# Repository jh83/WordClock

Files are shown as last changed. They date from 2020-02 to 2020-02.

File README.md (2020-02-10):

# WordClock

Some time ago i decided to build my own "WordClock" and I must say that im quite happy with the results:

Image of WordClock

The hardware consists of:

- ESP8266, as the "brain". Wifi and NTP connected and hosts a web page. Th webpage is used to configure time zone, NTP sync frequency, led strength among other things.
- ~~WS2812 LED strip cut to size to form a 14x10 matrix.~~ Custom made WS2813 LED panel (replaced the previous ws2812 strip due to dead led).
- Radar module (RCWL-0516) to detect movements. If movement isn't detected in a configurable amount of time (thru the web interface) then the LEDs are turned off.
  - Radar modules can "see thru" objects which makes it possible to mount behind the plywood front and have *working* results. Compared to PIR sensors that needs an open view.
- Lasercut 3mm plywood. A 40w laser was used in my case
- Mahogny frame. Cut from a bigger piece of wood and made into a frame.
- A white plastic bag used as a *diffuser* between the LED and the plywood front. You want this layer as thin as possible so that there isn't any light traveling to other characters thru the diffuser itself.
- A custom/modified stencil font family was created by me. A stencil font is required since parts of the letters otherwise will be lost after lasercutting

The size of the led matrix is around 9x9cm which makes each individual letter very small - around 6 mm tall and 5 mm wide.

You *might* be able to cut the plywood with a CNC router with a really tiny end mill, but the forces from the end mill might damage the tiny parts of the letters.

Tools/knowledge needed:

- A lasercutter (or ordering a custom laser cut part from internet).
- Basic woodworking tools and some wood glue.
- Basic knowledge about flashing Arduino code onto a ESP8266.
- Basic soldering skills.

Cost:

- Lasercut plywood.
  - Cheap if you own a laser cutter.
  - Price unknown if you need someone to lasercut it for you.
- LED Board
  - I had mine fabricated thru JLCPCB which also does assembly. The PCB with 140 WS2813, 140 capacitors and 140 resistors soldered onto it was about 17 USD plus shipping for a finished product.
- ESP8266.
  - I used a Wemos Mini pro since that was what I had in stock. Costs around 10 USD
- Radar sensor.
  - Around 2 USD
- Mahogny.
  - Expensive, atleast here in sweden.

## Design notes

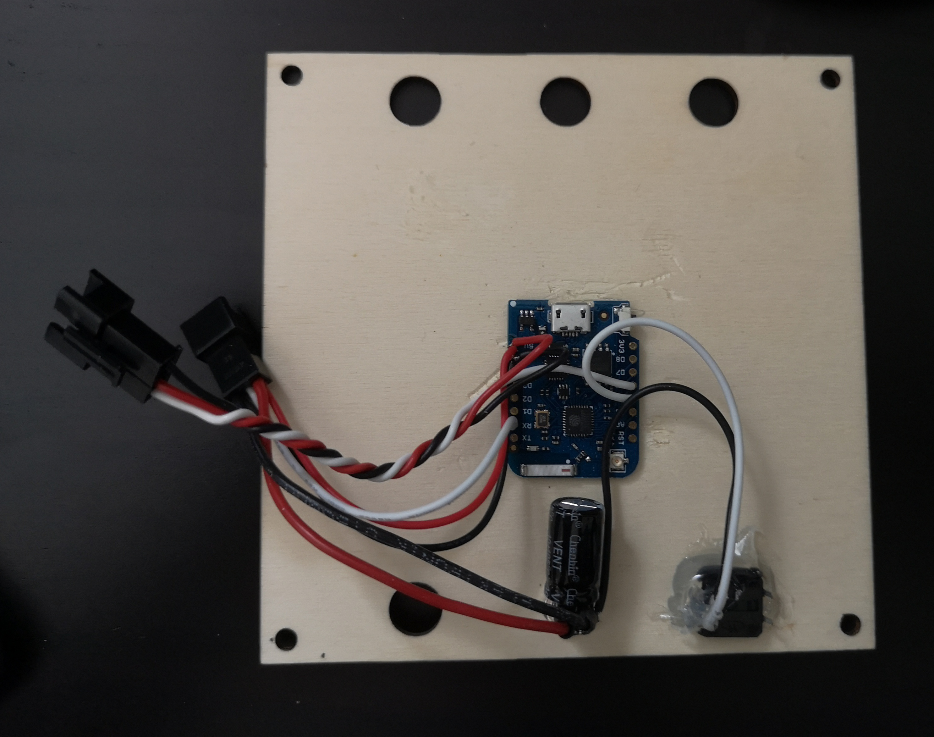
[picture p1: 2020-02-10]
images/backCoverWithElectronics.jpg

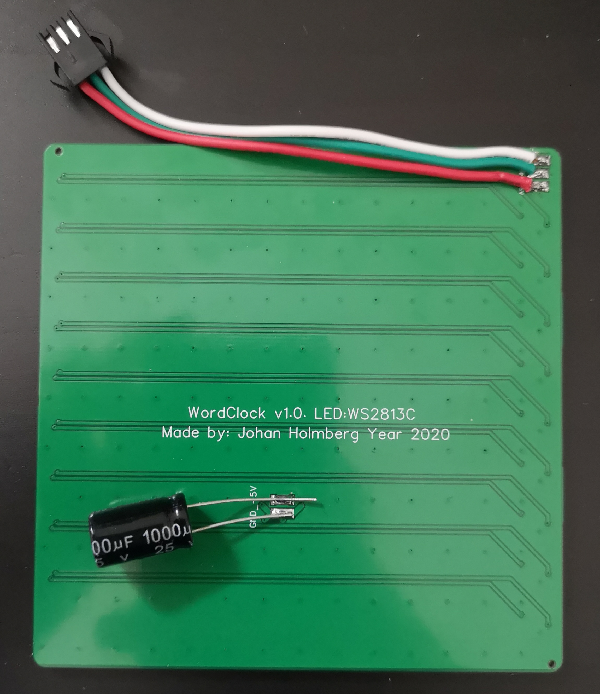
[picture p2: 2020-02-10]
images/ledPanelBack.jpg

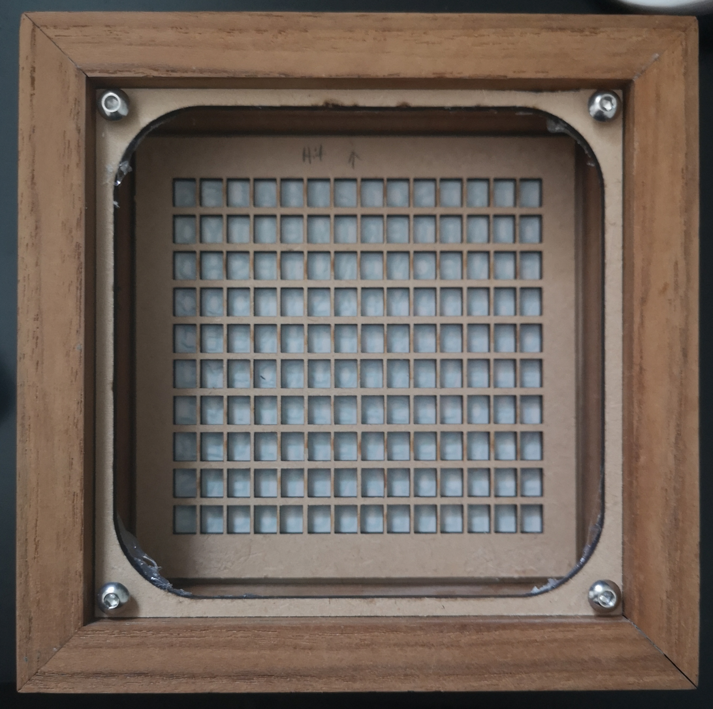
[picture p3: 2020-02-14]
images/Inside.jpg

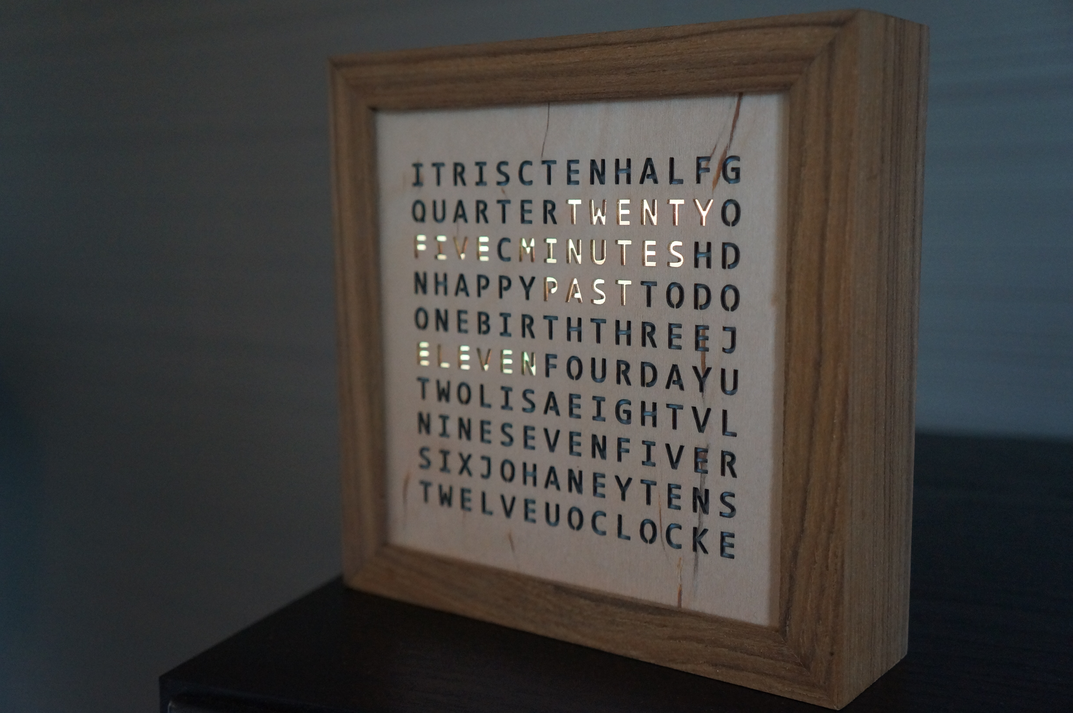
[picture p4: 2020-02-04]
images/WordClock_1_highres.JPG

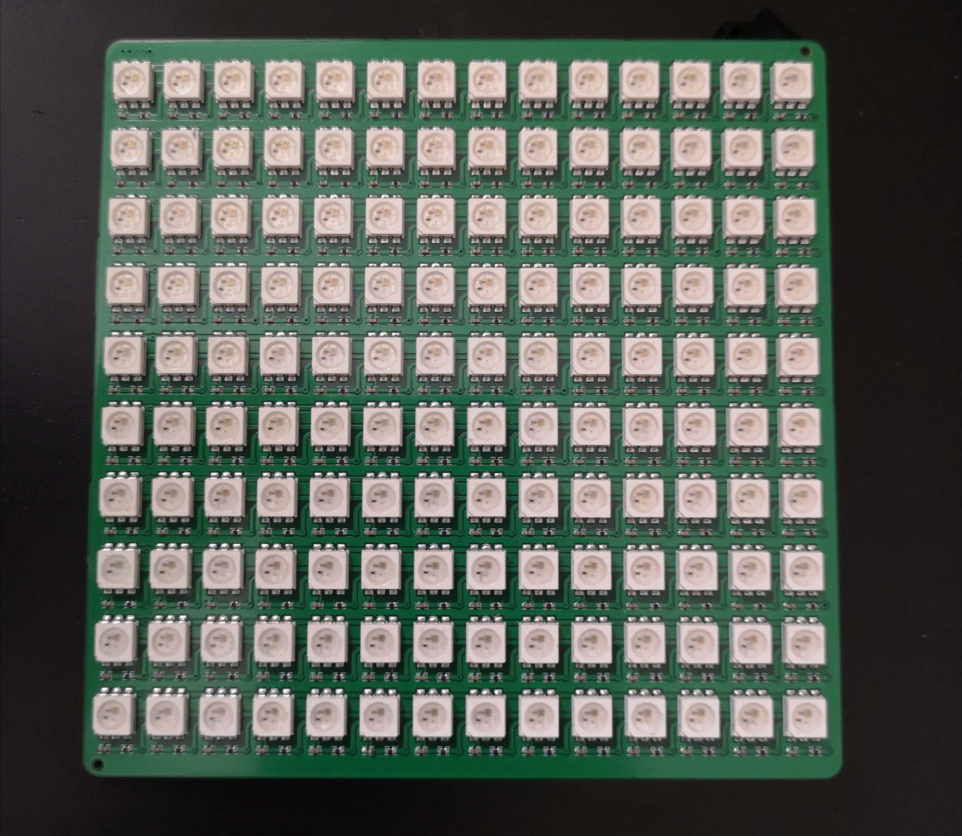
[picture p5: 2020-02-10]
images/ledPanelFront.jpg

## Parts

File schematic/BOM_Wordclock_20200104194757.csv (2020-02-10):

ID | Name | Designator | Footprint | Quantity | Manufacturer Part | Manufacturer | Supplier | Supplier Part | LCSC Assembly
2 | WS2813C | LED1,LED140,LED139,LED138,LED137,LED136,LED135,LED3,LED134,LED133,LED4,LED132,LED131,LED5,LED130,LED129,LED6,LED128,LED127,LED7,LED126,LED125,LED8,LED124,LED123,LED9,LED122,LED121,LED10,LED120,LED119,LED11,LED118,LED117,LED12,LED116,LED115,LED13,LED114,LED113,LED14,LED15,LED112,LED111,LED110,LED109,LED16,LED17,LED108,LED107,LED18,LED106,LED105,LED19,LED104,LED103,LED20,LED102,LED101,LED21,LED100,LED99,LED22,LED98,LED97,LED23,LED96,LED95,LED24,LED94,LED93,LED25,LED92,LED91,LED26,LED90,LED89,LED27,LED88,LED87,LED28,LED86,LED85,LED84,LED83,LED29,LED30,LED82,LED81,LED31,LED80,LED79,LED32,LED78,LED77,LED33,LED76,LED75,LED34,LED74,LED73,LED35,LED72,LED2,LED36,LED71,LED70,LED37,LED69,LED68,LED38,LED67,LED66,LED39,LED65,LED64,LED40,LED63,LED62,LED41,LED61,LED60,LED42,LED59,LED58,LED43,LED57,LED56,LED44,LED55,LED54,LED45,LED53,LED52,LED46,LED51,LED50,LED47,LED49,LED48 | LED-WS2813B-B | 140 | WS2813C | Worldsemi | LCSC | C194323
3 | 100nF | C48,C71,C49,C50,C46,C51,C52,C45,C53,C54,C44,C55,C56,C43,C57,C58,C42,C59,C60,C41,C61,C62,C40,C63,C64,C39,C65,C66,C38,C67,C68,C37,C69,C70,C36,C35,C72,C73,C34,C74,C75,C33,C76,C77,C32,C78,C79,C31,C80,C81,C30,C82,C29,C83,C84,C85,C28,C86,C87,C27,C88,C89,C26,C90,C91,C25,C92,C93,C24,C94,C47,C95,C23,C96,C97,C22,C98,C99,C21,C100,C101,C20,C102,C103,C19,C104,C105,C18,C106,C107,C17,C108,C16,C109,C110,C111,C15,C112,C14,C113,C114,C13,C115,C116,C12,C117,C118,C11,C119,C120,C10,C121,C122,C9,C123,C124,C8,C125,C126,C7,C127,C128,C6,C129,C130,C5,C131,C132,C4,C133,C134,C3,C135,C136,C137,C138,C2,C139,C1,C140 | 0402' | 140 | CL05B104KO5NNNC | SAMSUNG | LCSC | C1525 | Yes
5 | 200 | R23,R71,R95,R59,R41,R96,R22,R72,R97,R34,R44,R98,R21,R73,R99,R60,R48,R100,R20,R74,R101,R33,R54,R102,R19,R75,R103,R61,R40,R104,R18,R76,R105,R32,R49,R106,R17,R77,R107,R62,R51,R108,R78,R31,R109,R16,R55,R110,R15,R79,R111,R63,R39,R112,R80,R30,R113,R14,R43,R114,R81,R64,R115,R13,R45,R116,R82,R56,R117,R12,R65,R118,R83,R29,R119,R11,R38,R120,R84,R28,R121,R10,R46,R122,R85,R66,R123,R9,R52,R124,R86,R27,R125,R8,R57,R126,R87,R67,R127,R7,R37,R128,R88,R26,R129,R6,R42,R130,R89,R68,R131,R5,R47,R132,R90,R25,R133,R4,R58,R134,R91,R69,R135,R3,R36,R136,R2,R92,R137,R1,R24,R138,R50,R93,R139,R70,R53,R140,R35,R94 | 0402' | 140 | 0402WGF2000TCE | UniOhm | LCSC | C25087 | Yes

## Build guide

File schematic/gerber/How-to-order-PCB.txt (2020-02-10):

How to Order PCB

Please refer to:
https://docs.easyeda.com/en/PCB/Order-PCB

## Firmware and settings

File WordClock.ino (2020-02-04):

#include <Ticker.h>
#include <Time.h>
#include <TimeLib.h>
#include <ArduinoOTA.h>
#include <EEPROM.h>
#include <ESP8266WiFiMulti.h>
#include <WiFiUdp.h>
#include <ESP8266WiFi.h>
#include <WiFiServer.h>
#include <WiFiClient.h>
#include <ESP8266WebServer.h>
#include <ESP8266mDNS.h>

#include <ws2812_i2s.h>

#include "settings.h"
#include "mainPage.h"
//#include "display.h"
#include "ntp.h"
#include "staticScreens.h"

#define SETUP_PIN 14
#define RADAR_PIN 12

#define MODE_SETUP 0
#define MODE_CLOCK 1
int clockMode;
bool isUpdating = false;
bool debugEnabled = true;
long lastMovement = 0;
int movement = 0;
String lastMovementDateTime, lastMovementDate, lastMovementTime;

ESP8266WebServer server (80);

String httpUpdateResponse;

time_t prevDisplay = 0;

void setupAP() {
  Serial.println("Entering Setup Mode.");
  Serial.print("Initiating AP: ");
  Serial.println(WIFI_AP_NAME);
  Serial.println("IP: 192.168.4.1");
  clockMode = MODE_SETUP;
  WiFi.mode(WIFI_AP);
  WiFi.softAP(WIFI_AP_NAME);
  //  displayAP();
}


void setupSTA()
{
  char ssid[32];
  char psk[64];
  memset(ssid, 0, 32);
  memset(psk, 0, 64);
  // displayBusy(1);

  clockMode = MODE_CLOCK;
  WiFi.mode(WIFI_STA);

  settings.ssid.toCharArray(ssid, 32);
  settings.psk.toCharArray(psk, 64);
  if (WiFi.status() != WL_CONNECTED) {
    if (settings.psk.length()) {
      WiFi.begin(ssid, psk);
    } else {
      WiFi.begin(ssid);
    }
  }

  Serial.print("Connecting to SSID: ");
  Serial.println(ssid);

  // Wait for WiFi to connect
  while (WiFi.status() != WL_CONNECTED) {
    delay(1000);

    // Show the no WiFi screen
    showNoWifi();

    // Print some debug info
    Serial.print(WiFi.status());
    Serial.print(".");
  }

  // Once connected to WiFi
  Serial.print("Connected to WiFi. IP: ");
  Serial.println(WiFi.localIP());

  // Cleard the display
  clearDisplay();

  //  stopDisplayBusy();
  //  displayDash();
}

void setupWiFi() {
  // Wait up to 5s for GPIO0 to go low to enter AP/setup mode.
  //  displayBusy(0);
  while (millis() < 5000) {
    if (digitalRead(SETUP_PIN) == 0 || !settings.ssid.length()) {
      //      stopDisplayBusy();
      Serial.println("Setup Button pushed.");
      return setupAP();
    }
    delay(100);
  }
  //  stopDisplayBusy();
  setupSTA();
}


void handleRoot() {

  String s = MAIN_page;
  s.replace("@@SSID@@", settings.ssid);
  s.replace("@@PSK@@", settings.psk);
  s.replace("@@TZ@@", String(settings.timezone));
  s.replace("@@YEAR@@", String(year()));
  s.replace("@@MONTH@@", String(month()));
  s.replace("@@DAY@@", String(day()));
  s.replace("@@HOUR@@", String(hour()));
  s.replace("@@MIN@@", String(minute()));
  s.replace("@@SECOND@@", String(second()));
  s.replace("@@LASTMOVEMENT@@", lastMovementDateTime);
  s.replace("@@NTPSRV@@", settings.timeserver);
  s.replace("@@NTPINT@@", String(settings.interval));
  s.replace("@@SYNCSTATUS@@", timeStatus() == timeSet ? "OK" : "Overdue");
  s.replace("@@CLOCKNAME@@", settings.name);
  s.replace("@@ITIS@@", settings.showItIs == 1 ? "checked" : "");
  s.replace("@@DIMLVL@@", String(settings.dimLevel));
  s.replace("@@LEDTIME@@", String(settings.ledTime));
  s.replace("@@UPDATERESPONSE@@", httpUpdateResponse);
  httpUpdateResponse = "";
  server.send(200, "text/html", s);
}

void handleForm() {
  String update_wifi = server.arg("update_wifi");
  String t_ssid = server.arg("ssid");
  String t_psk = server.arg("psk");
  String t_timeserver = server.arg("ntpsrv");
  t_timeserver.toCharArray(settings.timeserver, EEPROM_TIMESERVER_LENGTH, 0);
  if (update_wifi == "1") {
    settings.ssid = t_ssid;
    settings.psk = t_psk;
  }
  String tz = server.arg("timezone");

  if (tz.length()) {
    settings.timezone = tz.toInt();
  }

  time_t newTime = getNtpTime();
  if (newTime) {
    setTime(newTime);
  }
  String syncInt = server.arg("ntpint");
  settings.interval = syncInt.toInt();

  settings.name = server.arg("clockname");
  settings.name.replace("+", " ");

  settings.showItIs = server.arg("showitis").toInt();

  settings.dimLevel = server.arg("dimlvl").toInt();

  settings.ledTime = server.arg("ledTime").toInt();

  httpUpdateResponse = "The configuration was updated.";

  server.sendHeader("Location", "/");
  server.send(302, "text/plain", "Moved");

  settings.Save();

  updateDisplay();

  if (update_wifi == "1") {
    delay(500);
    setupWiFi();
  }
}

void setup() {

  if (debugEnabled == true)
  {
    Serial.begin(115200);
    Serial.println();
    Serial.println("Booting");
  }

  //Load settings from EEPROM
  Serial.println("Loading settings from EEPROM");
  settings.Load();

  // Hostname defaults to esp8266-[ChipID]
  String deviceName = settings.name;
  char deviceNameToCharArray[sizeof(deviceName)];
  deviceName.toCharArray(deviceNameToCharArray, sizeof(deviceNameToCharArray));
  ArduinoOTA.setHostname(deviceNameToCharArray);
  //  ArduinoOTA.setHostname(deviceName);

  // No authentication by default
  // ArduinoOTA.setPassword((const char *)"123");

  ArduinoOTA.onStart([]() {
    Serial.println("Start");
    isUpdating = true;
  });
  ArduinoOTA.onEnd([]() {
    Serial.println("End");
    isUpdating = false;
  });
  ArduinoOTA.onProgress([](unsigned int progress, unsigned int total) {
    Serial.printf("Progress: %u%%\n", (progress / (total / 100)));
  });
  ArduinoOTA.onError([](ota_error_t error) {
    Serial.printf("Error[%u]: ", error);
    if (error == OTA_AUTH_ERROR) Serial.println("Auth Failed");
    else if (error == OTA_BEGIN_ERROR) Serial.println("Begin Failed");
    else if (error == OTA_CONNECT_ERROR) Serial.println("Connect Failed");
    else if (error == OTA_RECEIVE_ERROR) Serial.println("Receive Failed");
    else if (error == OTA_END_ERROR) Serial.println("End Failed");
    isUpdating = false;
  });
  ArduinoOTA.begin();

  // Initiate display and make sure that all LEDs are off
  leds.init(NUM_LEDS);
  clearDisplay();

  // Declare Pin Modes
  pinMode(SETUP_PIN, INPUT_PULLUP);
  pinMode(RADAR_PIN, INPUT);
  digitalWrite(SETUP_PIN, HIGH);

  // Attach the interrupt for the movement sensor
  attachInterrupt(RADAR_PIN, movementDetected, CHANGE);

  setupWiFi();
  setupTime();
  server.on("/", handleRoot);
  server.on("/form", handleForm);
  server.begin();
}


void loop() {
  ArduinoOTA.handle();
  server.handleClient();

  if (isUpdating == false)
  {
    //Serial.println("1");
    //if (displayIP()) return;
    if (clockMode == MODE_CLOCK) {
      if (timeStatus() != timeNotSet) {
        if (minute() != prevDisplay) { //update the display only if time has changed
          prevDisplay = minute();
          updateDisplay();
          //          displayClock();
        }
      }
    }

    //turn on/off display depending on movement
    // If movement is detected, then turn the display on by setting the dimLevel to configured level
    if (movement == 1)
    {
      movement = 2;
      settings.Load();
      updateDisplay();
    }

    // If no movement has been detected during the configured time, the turn the display off by lowering the dimLevel
    else if (movement == 2 && (lastMovement + (settings.ledTime * 60000)) < millis())
    {
      // Set the dim level to zero and then update the display to turn it off
      settings.dimLevel = 0;
      updateDisplay();

      // Set the movement flag back to 0
      movement = 0;
    }
  }
}

void movementDetected()
{
  movement = 1;
  lastMovement = millis();
  lastMovementDate = String(year()) + "-" + String(month()) + "-" + String(day());
  lastMovementTime = String(hour()) + ":" + String(minute()) + ":" + String(second());
  lastMovementDateTime = lastMovementDate + " " + lastMovementTime;
}

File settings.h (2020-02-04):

#include <EEPROM.h>

#ifndef SETTINGS_H
#define SETTINGS_H

#define EEPROM_WIFI_SIZE 512
#define EEPROM_MAGIC "NtPc"
#define EEPROM_MAGIC_OFFSET 0
#define EEPROM_MAGIC_LENGTH 4
#define EEPROM_SSID_OFFSET EEPROM_MAGIC_OFFSET + EEPROM_MAGIC_LENGTH
#define EEPROM_SSID_LENGTH 32
#define EEPROM_PSK_OFFSET EEPROM_SSID_OFFSET + EEPROM_SSID_LENGTH
#define EEPROM_PSK_LENGTH 64
#define EEPROM_TZ_OFFSET EEPROM_PSK_OFFSET + EEPROM_PSK_LENGTH
#define EEPROM_TIMESERVER_OFFSET EEPROM_TZ_OFFSET + 1
#define EEPROM_TIMESERVER_LENGTH 32
#define EEPROM_INTERVAL_OFFSET EEPROM_TIMESERVER_OFFSET + EEPROM_TIMESERVER_LENGTH
#define EEPROM_INTERVAL_LENGTH 2
#define EEPROM_NAME_OFFSET EEPROM_INTERVAL_OFFSET + EEPROM_INTERVAL_LENGTH
#define EEPROM_NAME_LENGTH 32
#define EEPROM_DIMLVL_OFFSET EEPROM_NAME_OFFSET + EEPROM_NAME_LENGTH
#define EEPROM_DIMLVL_LENGTH 1
#define EEPROM_SHOWITIS_OFFSET EEPROM_DIMLVL_OFFSET + EEPROM_DIMLVL_LENGTH
#define EEPROM_SHOWITIS_LENGTH 1
#define EEPROM_LEDTIME_OFFSET EEPROM_SHOWITIS_OFFSET + EEPROM_SHOWITIS_LENGTH

#define DEFAULT_TIMESERVER "time.nist.gov"
#define MINIMUM_INTERVAL 60

#define CLOCK_NAME "ESP-CLOCK"
#define WIFI_AP_NAME CLOCK_NAME

class Settings {

  public:
    Settings() {};

    void Load() {
      char buffer[EEPROM_WIFI_SIZE];
      EEPROM.begin(EEPROM_WIFI_SIZE);
      for (int i = 0 ; i < EEPROM_WIFI_SIZE ; i++) {
        buffer[i] = EEPROM.read(i);
      }
      EEPROM.end();

      // Verify magic;
      String magic;
      for (int i = EEPROM_MAGIC_OFFSET ; i < EEPROM_MAGIC_OFFSET + EEPROM_MAGIC_LENGTH ; i++) {
        magic += buffer[i];
      }
      if (magic != EEPROM_MAGIC) {
        return;
      }
      // Read SSID
      ssid = "";
      for (int i = EEPROM_SSID_OFFSET ; i < EEPROM_SSID_OFFSET + EEPROM_SSID_LENGTH ; i++) {
        if (buffer[i]) ssid += buffer[i];
      }
      // Read PSK
      psk = "";
      for (int i = EEPROM_PSK_OFFSET ; i < EEPROM_PSK_OFFSET + EEPROM_PSK_LENGTH ; i++) {
        if (buffer[i]) psk += buffer[i];
      }

      timezone = long(buffer[EEPROM_TZ_OFFSET]);

      strncpy(timeserver, &buffer[EEPROM_TIMESERVER_OFFSET], EEPROM_TIMESERVER_LENGTH);
      if (strlen(timeserver) < 1) {
        strcpy(timeserver, DEFAULT_TIMESERVER);
      }

      interval = time_t(buffer[EEPROM_INTERVAL_OFFSET]) << 8;
      interval |= buffer[EEPROM_INTERVAL_OFFSET + 1];
      if (interval < MINIMUM_INTERVAL) {
        interval = MINIMUM_INTERVAL;
      }
      // Clock name.
      name = "";
      for (int i = EEPROM_NAME_OFFSET ; i < EEPROM_NAME_OFFSET + EEPROM_NAME_LENGTH ; i++) {
        if (buffer[i]) name += buffer[i];
      }

      showItIs = long(buffer[EEPROM_SHOWITIS_OFFSET]);

      dimLevel = long(buffer[EEPROM_DIMLVL_OFFSET]);

      ledTime = long(buffer[EEPROM_LEDTIME_OFFSET]);

    }

    void Save() {
      unsigned char buffer[EEPROM_WIFI_SIZE];
      memset(buffer, 0, EEPROM_WIFI_SIZE);

      // Copy magic to buffer;
      strncpy((char *)buffer, EEPROM_MAGIC, EEPROM_MAGIC_LENGTH);

      // Copy SSID to buffer;
      ssid.getBytes(&buffer[EEPROM_SSID_OFFSET], EEPROM_SSID_LENGTH, 0);
      // Copy PSK to buffer.
      psk.getBytes(&buffer[EEPROM_PSK_OFFSET], EEPROM_PSK_LENGTH, 0);
      // Copy timezone.
      buffer[EEPROM_TZ_OFFSET] = timezone;
      // Copy timeserver.
      strncpy((char *)&buffer[EEPROM_TIMESERVER_OFFSET], (char *)timeserver, EEPROM_TIMESERVER_LENGTH);
      // Copy interval.
      buffer[EEPROM_INTERVAL_OFFSET] = interval >> 8;
      buffer[EEPROM_INTERVAL_OFFSET + 1] = interval & 0xff;
      // Copy clock name.
      name.getBytes(&buffer[EEPROM_NAME_OFFSET], EEPROM_NAME_LENGTH, 0);
      // Copy dimLevel
      buffer[EEPROM_DIMLVL_OFFSET] = dimLevel;
      // Copy showItIs
      buffer[EEPROM_SHOWITIS_OFFSET] = showItIs;
      // Copy Led On-Time
      buffer[EEPROM_LEDTIME_OFFSET] = ledTime;

      // Write to EEPROM
      EEPROM.begin(EEPROM_WIFI_SIZE);
      for (int i = 0 ; i < EEPROM_WIFI_SIZE ; i++) {
        EEPROM.write(i, buffer[i]);
      }
      EEPROM.end();
    }

    String ssid;
    String psk;
    long timezone;
    char timeserver[64];
    int interval;
    String name;
    int dimLevel;
    int showItIs;
    int ledTime;
};

Settings settings;

#endif
